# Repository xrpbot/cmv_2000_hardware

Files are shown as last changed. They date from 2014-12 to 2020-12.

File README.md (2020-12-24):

CMV2000 adapter kit
===================

This adapter kit allows connecting an [AMS CMV2000](https://ams.com/cmv2000)
image sensor to a ZedBoard (and probably other FPGA devboards) via the [FPGA
Mezzanine Card (FMC)](https://en.wikipedia.org/wiki/FPGA_Mezzanine_Card)
connector.

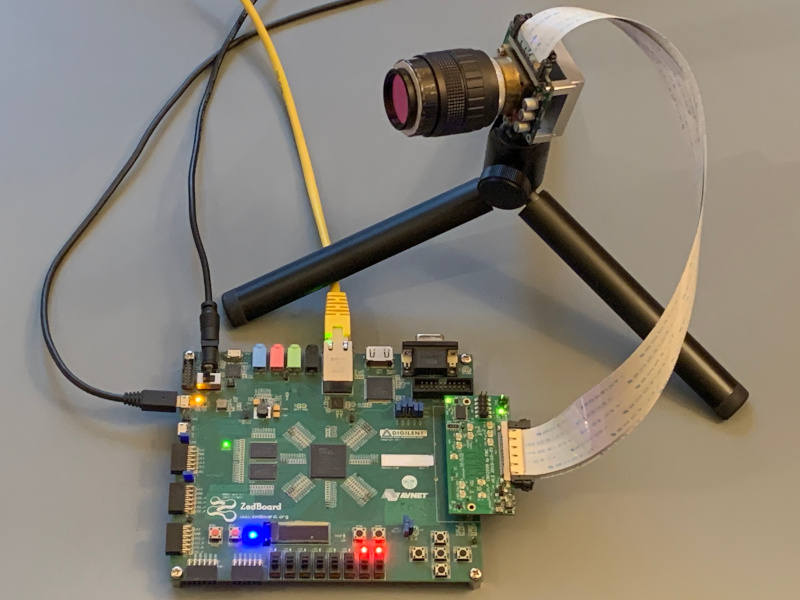
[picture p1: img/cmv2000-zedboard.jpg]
Image: CMV2000 sensor and ZedBoard


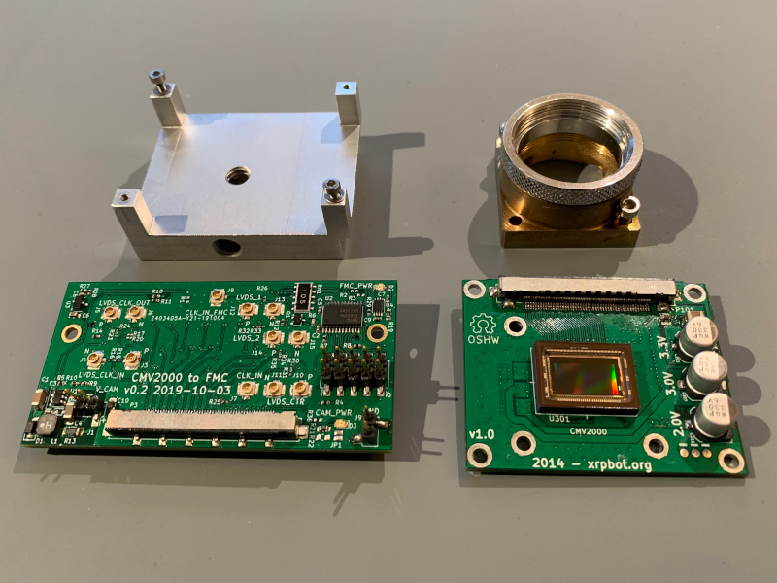
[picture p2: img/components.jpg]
Image: PCBs and machined parts


The CMV2000 is a high-speed image sensor intended for machine vision
applications (2 megapixels, 340 fps). While relatively expensive, it is one of
the few mid-range image sensors where reasonably complete documentation is
freely available (without NDA) from the manufacturer.

The hardware is split in two PCBs, connected by two high speed flat flex
cables. The first board contains the sensor, the second board connects to the
FMC port on the ZedBoard.

The sensor is powered by the ZedBoard, using the 12 V supply provided on the FMC
connector. Level shifters are used to translate all single-ended signals from
the FPGA I/O voltage to the 3.3 V used by the sensor.

The FMC board contains integrated 1k probes for some of the high-speed
differential signals. Additionally, a pin header allows probing the low-speed
single-ended signals.

For space reasons, the 1k probes use U.FL connectors for the connection to the
oscilloscope. The U.FL connectors have a very limited number of mating cycles
and the number of connections must therefore be kept to a minimum. Note that a
1k probe generally requires a termination (typically 50 Ω) at the oscilloscope;
with a high-impedance input, results will be very poor. If the 1k probes are
not required, the connectors and the corresponding resistors can simply be left
unpopulated.

See [pinmap.txt](pinmap.txt) for a list of connections from FPGA package pins
to camera pins.

Note that this repository uses submodules.

FMC board
---------

### Stackup

The FMC PCB is designed to be produced with 4 layers using the
[JLCPCB](https://jlcpcb.com/) JLC2313 stackup. (0.1 mm prepreg, ε<sub>r</sub> =
4.05 between the outer and inner layer.)

Using the JLCPCB impedance calculator, the following trace parameters were obtained:

100 Ω differential:
4.00 mil (102 µm) trace width / 5.00 mil (127 µm) space

50 Ω single-ended:
5.78 mil (147 µm) trace width

These results were cross-checked using Maarten Baerts [AlterPCB
TLineSim](https://www.maartenbaert.be/alterpcb/tlinesim/) tool. In addition,
the influence of ground pour on the signal layer was investigated (using the
"Coplanar Waveguide" geometry). A distance of >= 200 µm between the edge of the
signal trace and ground seems to have little effect on the impedance.

### Vias

JLC multilayer: min. via drill: 0.2 mm, min. via diameter: 0.45 mm

Known issues
------------

* Sensor board: The 3.0 V rail is generated with an LDO (U202) from the 3.3 V
rail. However, this drop is too low for the LDO to properly operate. On the
physical board, this is fixed with a bodge wire connecting the input of U202 to
the 5.0 V rail instead. However, this fix is not contained in the schematic or
layout.

* After the sensor board PCB was produced, we found out that the intended
31-pin connector (P102) was no longer available. Thus, a 41-pin connector had
to be bodged on (sacrificing the I2C EEPROM). This change is not documented in
the schematic. However, when the current version of the FMC board was designed,
it was adapted to the situation and uses a 41-pin connector. The end result is
that the boards, as found in this repository, are incompatible: the sensor
board uses a 51-pin and a 31-pin connector, while the FMC board uses a 51-pin
and a 41-pin connector.

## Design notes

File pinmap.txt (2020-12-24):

VHDL (Note 1)         Zynq_pkg Zynq                          Zedboard       FMC    JST/Adapter    JST/Camera    CMV2000           Comment

                                                                            n/a    J51/51         J51/1         LED
                                                                            -      J51/50         J51/2         EEPROM_A0
                      U7       Bank13-IO_25                  FMC-SDA        C31    J51/49         J51/3         EEPROM_SDA        optional (jumper)
                      R7       Bank13-IO_0                   FMC-SCL        C30    J51/48         J51/4         EEPROM_SCL        optional (jumper)

                      R19      Bank34-IO_L22P_T3             FMC-LA10_P     C14    CAM_PWR_ON     -             -                 optional (jumper)
                      P17      Bank34-IO_L20P_T3             FMC-LA02_P     H7     CAM_PWR_GOOD   -             -                 optional (jumper)

cmv_sys_res_n         T19      Bank34-IO_L22N_T3             FMC-LA10_N     C15    J51/47         J51/5         SYS_RES_N

spi_en                K20      Bank34-IO_L11N_T1_SRCC        FMC-LA14_N     C19    J51/43         J51/9         SPI_EN
spi_clk               K19      Bank34-IO_L11P_T1_SRCC        FMC-LA14_P     C18    J51/45         J51/7         SPI_CLK
spi_in                C20      Bank35-IO_L14N_T2_AD4N_SRCC   FMC-LA18_CC_N  C23    J51/39         J51/13        SPI_IN
spi_out               D20      Bank35-IO_L14P_T2_AD4P_SRCC   FMC-LA18_CC_P  C22    J51/41         J51/11        SPI_OUT

cmv_clk_in            E21      Bank35-IO_L17P_T2_AD5P        FMC-LA27_P     C26    J51/31         J51/21        CLK_IN
cmv_t_exp1            L21      Bank34-IO_L10P_T1             FMC-LA06_P     C10    J51/37         J51/15        T_EXP1            pin assignment changed (Note 2)
cmv_t_exp2            L22      Bank34-IO_L10N_T1             FMC-LA06_N     C11    J51/35         J51/17        T_EXP2            pin assignment changed (Note 2)
cmv_frame_req         D21      Bank35-IO_L17N_T2_AD5N        FMC-LA27_N     C27    J51/33         J51/19        FRAME_REQ

cmv_lvds_outclk_n     C19      Bank35-IO_L12N_T1_MRCC        FMC-CLK1_N     G3     J51/2          J51/50        LVDS_CLK_OUT_N
cmv_lvds_outclk_p     D18      Bank35-IO_L12P_T1_MRCC        FMC-CLK1_P     G2     J51/1          J51/51        LVDS_CLK_OUT_P

cmv_lvds_clk_n        L19      Bank34-IO_L12N_T1_MRCC        FMC-CLK0_N     H5     J41/16         J31/26        LVDS_CLK_IN_N     optional (jumper)
cmv_lvds_clk_p        L18      Bank34-IO_L12P_T1_MRCC        FMC-CLK0_P     H4     J41/17         J31/25        LVDS_CLK_IN_P     optional (jumper)

cmv_lvds_ctrl_n       A22      Bank35-IO_L15N_T2_DQS_AD12N   FMC-LA32_N     H38    J51/29         J51/23        LVDS_CTR_N
cmv_lvds_ctrl_p       A21      Bank35-IO_L15P_T2_DQS_AD12P   FMC-LA32_P     H37    J51/28         J51/24        LVDS_CTR_P

cmv_lvds_data_n[0]    E18      Bank35-IO_L5N_T0_AD9N         FMC-LA26_N     D27    J41/19         J31/23        LVDS_1_N
cmv_lvds_data_p[0]    F18      Bank35-IO_L5P_T0_AD9P         FMC-LA26_P     D26    J41/20         J31/22        LVDS_1_P
cmv_lvds_data_n[1]    B15      Bank35-IO_L7N_T1_AD2N         FMC-LA30_N     H35    J51/26         J51/26        LVDS_2_N
cmv_lvds_data_p[1]    C15      Bank35-IO_L7P_T1_AD2P         FMC-LA30_P     H34    J51/25         J51/27        LVDS_2_P
cmv_lvds_data_n[2]    A19      Bank35-IO_L10N_T1_AD11N       FMC-LA24_N     H29    J51/20         J51/32        LVDS_3_N
cmv_lvds_data_p[2]    A18      Bank35-IO_L10P_T1_AD11P       FMC-LA24_P     H28    J51/19         J51/33        LVDS_3_P
cmv_lvds_data_n[3]    A17      Bank35-IO_L9N_T1_DQS_AD3N     FMC-LA28_N     H32    J51/23         J51/29        LVDS_4_N
cmv_lvds_data_p[3]    A16      Bank35-IO_L9P_T1_DQS_AD3P     FMC-LA28_P     H31    J51/22         J51/30        LVDS_4_P
cmv_lvds_data_n[4]    D15      Bank35-IO_L3N_T0_DQS_AD1N     FMC-LA23_N     D24    J41/22         J31/20        LVDS_5_N
cmv_lvds_data_p[4]    E15      Bank35-IO_L3P_T0_DQS_AD1P     FMC-LA23_P     D23    J41/23         J31/19        LVDS_5_P
cmv_lvds_data_n[5]    B20      Bank35-IO_L13N_T2_MRCC        FMC-LA17_CC_N  D21    J41/25         J31/17        LVDS_6_N
cmv_lvds_data_p[5]    B19      Bank35-IO_L13P_T2_MRCC        FMC-LA17_CC_P  D20    J41/26         J31/16        LVDS_6_P
cmv_lvds_data_n[6]    J17      Bank34-IO_L2N_T0              FMC-LA15_N     H20    J51/11         J51/41        LVDS_7_N
cmv_lvds_data_p[6]    J16      Bank34-IO_L2P_T0              FMC-LA15_P     H19    J51/10         J51/42        LVDS_7_P
cmv_lvds_data_n[7]    E20      Bank35-IO_L21N_T3_DQS_AD14N   FMC-LA21_N     H26    J51/17         J51/35        LVDS_8_N
cmv_lvds_data_p[7]    E19      Bank35-IO_L21P_T3_DQS_AD14P   FMC-LA21_P     H25    J51/16         J51/36        LVDS_8_P
cmv_lvds_data_n[8]    G16      Bank35-IO_L4N_T0              FMC-LA19_N     H23    J51/14         J51/38        LVDS_9_N
cmv_lvds_data_p[8]    G15      Bank35-IO_L4P_T0              FMC-LA19_P     H22    J51/13         J51/39        LVDS_9_P
cmv_lvds_data_n[9]    N18      Bank34-IO_L5N_T0              FMC-LA11_N     H17    J51/8          J51/44        LVDS_10_N
cmv_lvds_data_p[9]    N17      Bank34-IO_L5P_T0              FMC-LA11_P     H16    J51/7          J51/45        LVDS_10_P
cmv_lvds_data_n[10]   M17      Bank34-IO_L4N_T0              FMC-LA13_N     D18    J41/28         J31/14        LVDS_11_N
cmv_lvds_data_p[10]   L17      Bank34-IO_L4P_T0              FMC-LA13_P     D17    J41/29         J31/13        LVDS_11_P
cmv_lvds_data_n[11]   R21      Bank34-IO_L17N_T2             FMC-LA09_N     D15    J41/31         J31/11        LVDS_12_N
cmv_lvds_data_p[11]   R20      Bank34-IO_L17P_T2             FMC-LA09_P     D14    J41/32         J31/10        LVDS_12_P
cmv_lvds_data_n[12]   M22      Bank34-IO_L15N_T2_DQS         FMC-LA04_N     H11    J51/5          J51/47        LVDS_13_N
cmv_lvds_data_p[12]   M21      Bank34-IO_L15P_T2_DQS         FMC-LA04_P     H10    J51/4          J51/48        LVDS_13_P
cmv_lvds_data_n[13]   K18      Bank34-IO_L7N_T1              FMC-LA05_N     D12    J41/34         J31/8         LVDS_14_N
cmv_lvds_data_p[13]   J18      Bank34-IO_L7P_T1              FMC-LA05_P     D11    J41/35         J31/7         LVDS_14_P
cmv_lvds_data_n[14]   T17      Bank34-IO_L21N_T3_DQS         FMC-LA07_N     H14    J41/40         J31/2         LVDS_15_N
cmv_lvds_data_p[14]   T16      Bank34-IO_L21P_T3_DQS         FMC-LA07_P     H13    J41/41         J31/1         LVDS_15_P
cmv_lvds_data_n[15]   N20      Bank34-IO_L14N_T2_SRCC        FMC-LA01_CC_N  D9     J41/37         J31/5         LVDS_16_N
cmv_lvds_data_p[15]   N19      Bank34-IO_L14P_T2_SRCC        FMC-LA01_CC_P  D8     J41/38         J31/4         LVDS_16_P

Note 1: The "VHDL" column refers to the Apertus gateware.
Note 2: Pin assignment changed with respect to the obsolete v0.1 of the FMC adapter board.

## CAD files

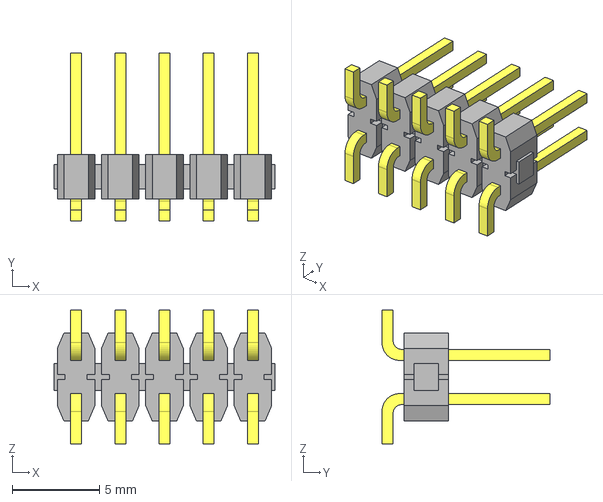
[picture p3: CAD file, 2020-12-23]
fmc_board/3dmodels/TSM-105-01-L-DV.stp
12.7 x 9.65 x 7.70 mm
_TSM-105-01-DV_body
_T-1S6-16(-01-5-DV)

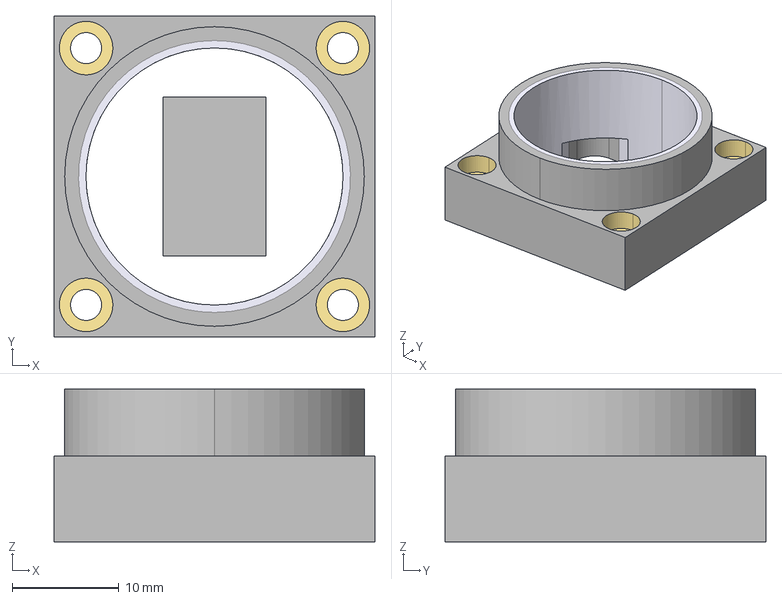
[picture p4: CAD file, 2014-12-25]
mount/c-mount.stp
30.0 x 30.0 x 14.3 mm

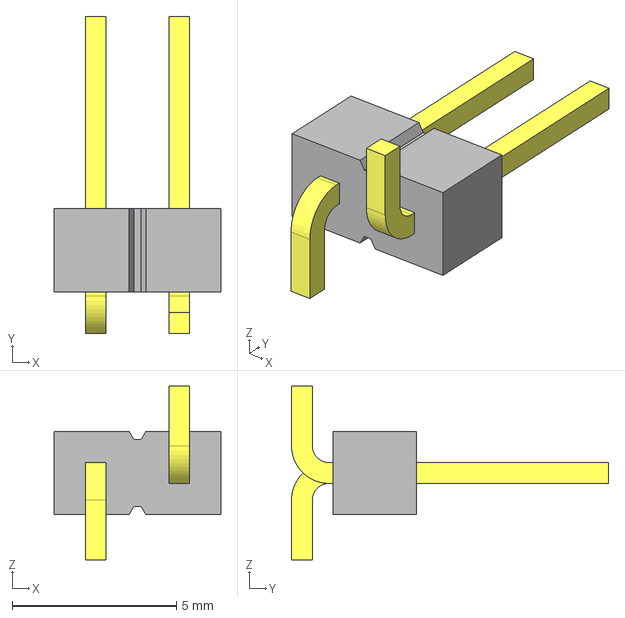
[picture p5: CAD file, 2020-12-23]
fmc_board/3dmodels/TSM-102-01-L-SV.stp
5.08 x 9.65 x 5.28 mm
_TSM-102-01-SV_body
_T-1S6-16(-01-2-SV)

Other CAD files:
mount/c-mount.stl

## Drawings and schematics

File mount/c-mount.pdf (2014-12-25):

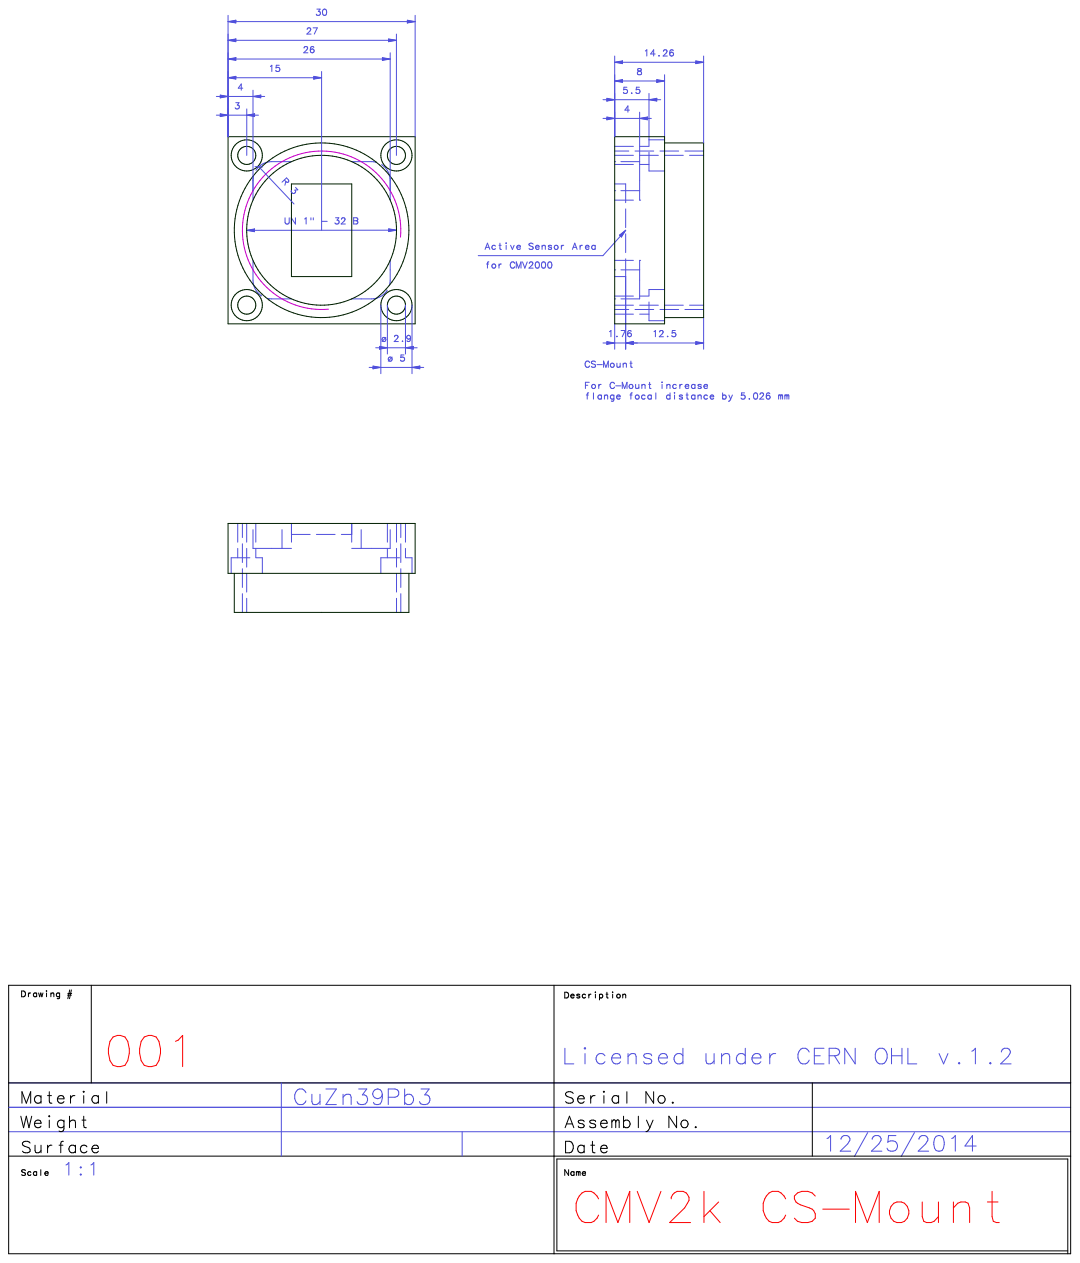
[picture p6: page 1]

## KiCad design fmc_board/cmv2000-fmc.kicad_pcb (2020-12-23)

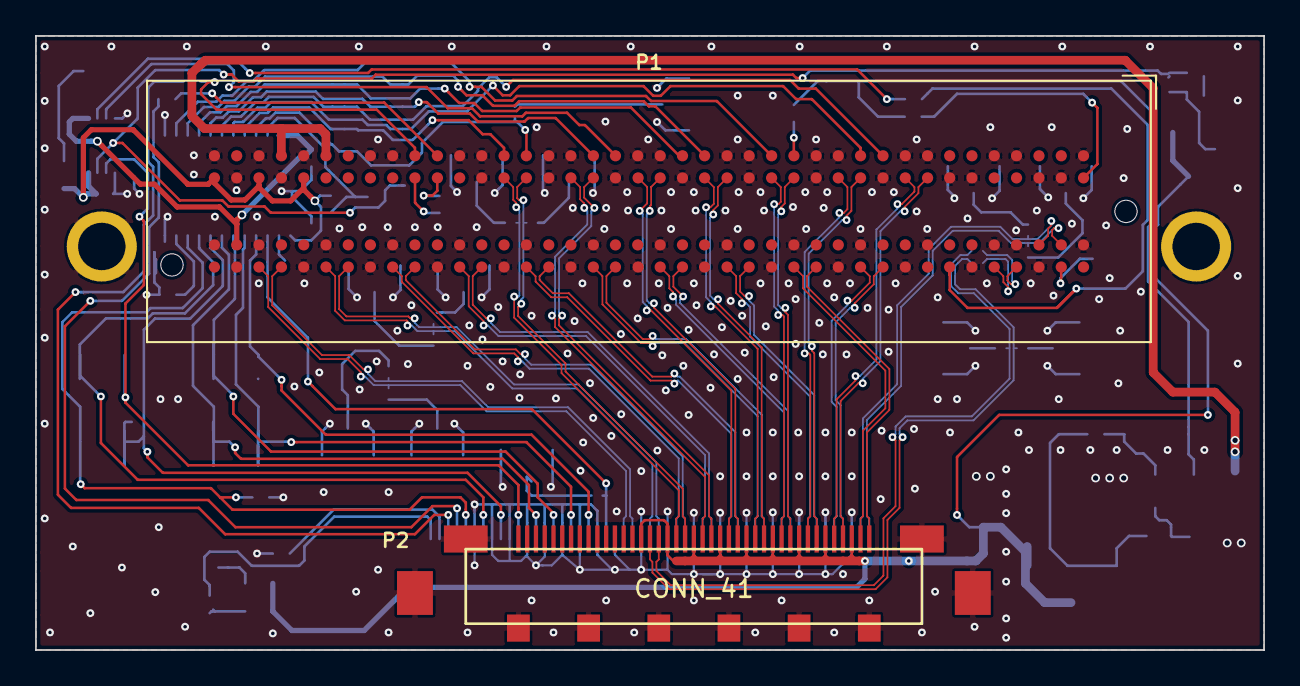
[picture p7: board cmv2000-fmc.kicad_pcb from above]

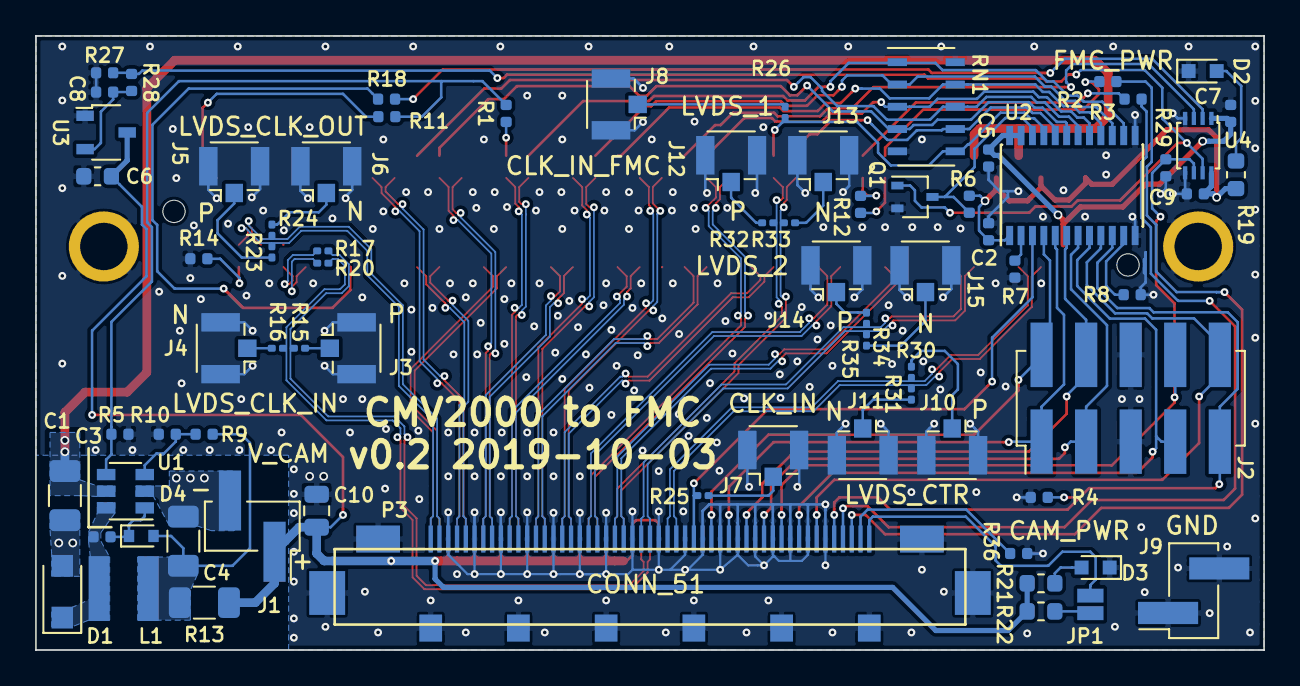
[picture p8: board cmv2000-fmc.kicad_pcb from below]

Board: 4 copper layers, 70.0 x 35.0 mm, 76 parts (74 on the bottom side), 101 nets.

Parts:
C1: 10uF, 25V; C_1206_3216Metric
C2, C5, C7, C9: 100n; C_0402_1005Metric
C3: 10n; C_0402_1005Metric
C4: 22uF, 10V; C_1206_3216Metric
C6: 1u; C_0603_1608Metric
C8: 1n; C_0402_1005Metric
C10: TBD; C_0805_2012Metric
D1: D; NRVTS245ESF
D2, D3: LED; 150060VS75000
D4: D; D_SOD-523
J1, J9: Conn_01x02; TSM-102-01-L-SV
J2: Conn_02x05; TSM-105-01-L-DV
J3: LVDS_CLK_IN_P; U.FL_Hirose_U.FL-R-SMT-1_Vertical
J4: LVDS_CLK_IN_N; U.FL_Hirose_U.FL-R-SMT-1_Vertical
J5: LVDS_CLK_OUT_P; U.FL_Hirose_U.FL-R-SMT-1_Vertical
J6: LVDS_CLK_OUT_N; U.FL_Hirose_U.FL-R-SMT-1_Vertical
J7, J8: CLK_IN; U.FL_Hirose_U.FL-R-SMT-1_Vertical
J10: LVDS_CTR_P; U.FL_Hirose_U.FL-R-SMT-1_Vertical
J11: LVDS_CTR_N; U.FL_Hirose_U.FL-R-SMT-1_Vertical
J12: LVDS_1_P; U.FL_Hirose_U.FL-R-SMT-1_Vertical
J13: LVDS_1_N; U.FL_Hirose_U.FL-R-SMT-1_Vertical
J14: LVDS_2_P; U.FL_Hirose_U.FL-R-SMT-1_Vertical
J15: LVDS_2_N; U.FL_Hirose_U.FL-R-SMT-1_Vertical
JP1: JUMPER; SOLDERSW_2
L1: 4.7uH; NRS4018
P1: FMC_LPC; Samtec_FMC_ASP-134604-01_4x40_Vertical
P2: CONN_41; FI-RE41S-HF-R1500
P3: CONN_51; FI-RE51S-HF-R1500
Q1: Q_NMOS_GSD; SOT-323_SC-70
R1, R2, R3, R36: DNP; R_0402_1005Metric
R4, R5, R6, R7, R8, R28: 10k; R_0402_1005Metric
R9: 49.9k; R_0402_1005Metric
R10: 9.53k; R_0402_1005Metric
R11, R12, R14, R18: 0; R_0402_1005Metric
R13: 0; R_1206_3216Metric
R15, R16, R23, R24, R25, R26, R30, R31, R32, R33, R34, R35: 1k; R_0201_0603Metric
R17, R20: DNP; R_0201_0603Metric
R19: 270R; R_0603_1608Metric
R21: 620R; R_0603_1608Metric
R22: TBD; R_0603_1608Metric
R27: 33k; R_0402_1005Metric
R29: 1M; R_0402_1005Metric
RN1: R_NET_BUS_8, 1M; EXB-A10P
U1: AP3211; SOT-23-6
U2: SN74AXC8T245; TSSOP-24_4.4x7.8mm_P0.65mm
U3: BD49xxx_GND1; SSOP3
U4: SN74LVC2T45; VSSOP-8_2.4x2.1mm_P0.5mm

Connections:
+3V3: C2.1, C9.1, P1.D36, P1.D38, P1.D40, R6.1, R19.1, U2.1, U4.8
+12V: C1.1, P1.C35, P1.C37, U1.5
/5V_CAM: C6.1, C10.1, J1.1, P2.15, P2.18, P2.21, P2.24, P2.27, P2.30, P2.33, P2.36, P2.39, R13.1, R21.1, R22.2, U3.3
/A0: P3.50, R36.2
/CAM_PWR_GOOD: Q1.1, R27.1, R28.1, U4.7
/CAM_PWR_GOOD_FMC: R18.1, U4.2
/CAM_PWR_ON: R1.2, R5.1, R11.1, U1.4
/CLK_IN: P3.31, R25.2, U2.3
/CLK_IN_FMC: P1.C26, R26.2, RN1.6, U2.21
/FRAME_REQ: J2.2, P3.33, U2.4
/FRAME_REQ_FMC: P1.C27, RN1.7, U2.20
/LED: JP1.2, P3.51
/LVDS_1_N: P1.D27, P2.19, R33.2
/LVDS_1_P: P1.D26, P2.20, R32.2
/LVDS_2_N: P1.H35, P3.26, R35.2
/LVDS_2_P: P1.H34, P3.25, R34.2
/LVDS_3_N: P1.H29, P3.20
/LVDS_3_P: P1.H28, P3.19
/LVDS_4_N: P1.H32, P3.23
/LVDS_4_P: P1.H31, P3.22
/LVDS_5_N: P1.D24, P2.22
/LVDS_5_P: P1.D23, P2.23
/LVDS_6_N: P1.D21, P2.25
/LVDS_6_P: P1.D20, P2.26
/LVDS_7_N: P1.H20, P3.11
/LVDS_7_P: P1.H19, P3.10
/LVDS_8_N: P1.H26, P3.17
/LVDS_8_P: P1.H25, P3.16
/LVDS_9_N: P1.H23, P3.14
/LVDS_9_P: P1.H22, P3.13
/LVDS_10_N: P1.H17, P3.8
/LVDS_10_P: P1.H16, P3.7
/LVDS_11_N: P1.D18, P2.28
/LVDS_11_P: P1.D17, P2.29
/LVDS_12_N: P1.D15, P2.31
/LVDS_12_P: P1.D14, P2.32
/LVDS_13_N: P1.H11, P3.5
/LVDS_13_P: P1.H10, P3.4
/LVDS_14_N: P1.D12, P2.34
/LVDS_14_P: P1.D11, P2.35
/LVDS_15_N: P1.H14, P2.40
/LVDS_15_P: P1.H13, P2.41
/LVDS_16_N: P1.D09, P2.37
/LVDS_16_P: P1.D08, P2.38
/LVDS_CLK_IN_0_N: P1.H05, R20.2
/LVDS_CLK_IN_0_P: P1.H04, R17.2
/LVDS_CLK_IN_N: P2.16, R16.2, R20.1
/LVDS_CLK_IN_P: P2.17, R15.2, R17.1
/LVDS_CLK_OUT_N: P1.G03, P3.2, R24.2
/LVDS_CLK_OUT_P: P1.G02, P3.1, R23.2
/LVDS_CTR_N: P1.H38, P3.29, R31.2
/LVDS_CTR_P: P1.H37, P3.28, R30.2
/SCL: P3.48, R3.2
/SDA: P3.49, R2.2
/SPI_CLK: J2.10, P3.45, U2.9
/SPI_CLK_FMC: P1.C18, RN1.2, U2.15
/SPI_EN: J2.7, P3.43, U2.8
/SPI_EN_FMC: P1.C19, RN1.9, U2.16
/SPI_IN: J2.3, P3.39, U2.7
/SPI_IN_FMC: P1.C23, RN1.3, U2.17
/SPI_OUT: J2.8, P3.41, R29.1, U4.6
/SPI_OUT_FMC: P1.C22, U4.3
/SYS_RES_N: J2.9, P3.47, R4.1, U2.10
/SYS_RES_N_FMC: P1.C15, RN1.1, U2.14
/T_EXP1: J2.4, P3.37, U2.6
/T_EXP1_FMC: P1.C10, RN1.8, U2.18
/T_EXP2: J2.1, P3.35, U2.5
/T_EXP2_FMC: P1.C11, RN1.4, U2.19
/VIO_FMC: C5.1, C7.1, P1.G39, U2.23, U2.24, U4.1
GND: C1.2, C2.2, C4.2, C5.2, C6.2, C7.2, C8.2, C9.2, C10.2, D1.2, D2.1, D3.1, J1.2, J2.5, J2.6, J3.2, J4.2, J5.2, J6.2, J7.2, J8.2, J9.1, J9.2, J10.2, J11.2, J12.2, J13.2, J14.2, J15.2, P1.C01, P1.C04, P1.C05, P1.C08, P1.C09, P1.C12, P1.C13, P1.C16, P1.C17, P1.C20, P1.C21, P1.C24, P1.C25, P1.C28, P1.C29, P1.C32, P1.C33, P1.C36, P1.C38, P1.C40, P1.D02, P1.D03, P1.D06, P1.D07, P1.D10, P1.D13, P1.D16, P1.D19, P1.D22, P1.D25, P1.D28, P1.D37, P1.D39, P1.G01, P1.G04, P1.G05, P1.G08, P1.G11, P1.G14, P1.G17, P1.G20, P1.G23, P1.G26, P1.G29, P1.G32, P1.G35, P1.G38, P1.G40, P1.H03, P1.H06, P1.H09, P1.H12, P1.H15, P1.H18, P1.H21, P1.H24, P1.H27, P1.H30, P1.H33, P1.H36, P1.H39, P2.SH, P3.3, P3.6, P3.9, P3.12, P3.15, P3.18, P3.21, P3.24, P3.27, P3.30, P3.32, P3.34, P3.36, P3.38, P3.40, P3.42, P3.44, P3.46, P3.SH, Q1.2, R4.2, R5.2, R7.2, R8.2, R10.2, R14.1, R27.2, R29.2, R36.1, RN1.5, RN1.10, U1.2, U2.12, U2.13, U3.1, U4.4, U4.5
unnamed: C3.1, D4.1, U1.1
unnamed: C3.2, D1.1, L1.1, U1.6
unnamed: C4.1, D4.2, L1.2, R9.1, R13.2
unnamed: C8.1, R28.2, U3.2
unnamed: D2.2, R19.2
unnamed: D3.2, R21.2
unnamed: J3.1, R15.1
unnamed: J4.1, R16.1
unnamed: J5.1, R23.1
unnamed: J6.1, R24.1
unnamed: J7.1, R25.1
unnamed: J8.1, R26.1
unnamed: J10.1, R30.1
unnamed: J11.1, R31.1
unnamed: J12.1, R32.1
unnamed: J13.1, R33.1
unnamed: J14.1, R34.1
unnamed: J15.1, R35.1
unnamed: JP1.1, R22.1
unnamed: P1.C14, R1.1
unnamed: P1.C30, R3.1
unnamed: P1.C31, R2.1
unnamed: P1.D01, R11.2
unnamed: P1.D30, R12.1
unnamed: P1.D31, R12.2
unnamed: P1.H02, R14.2
unnamed: P1.H07, R18.2
unnamed: Q1.3, R6.2, U2.22
unnamed: R7.1, U2.2
unnamed: R8.1, U2.11
unnamed: R9.2, R10.1, U1.3

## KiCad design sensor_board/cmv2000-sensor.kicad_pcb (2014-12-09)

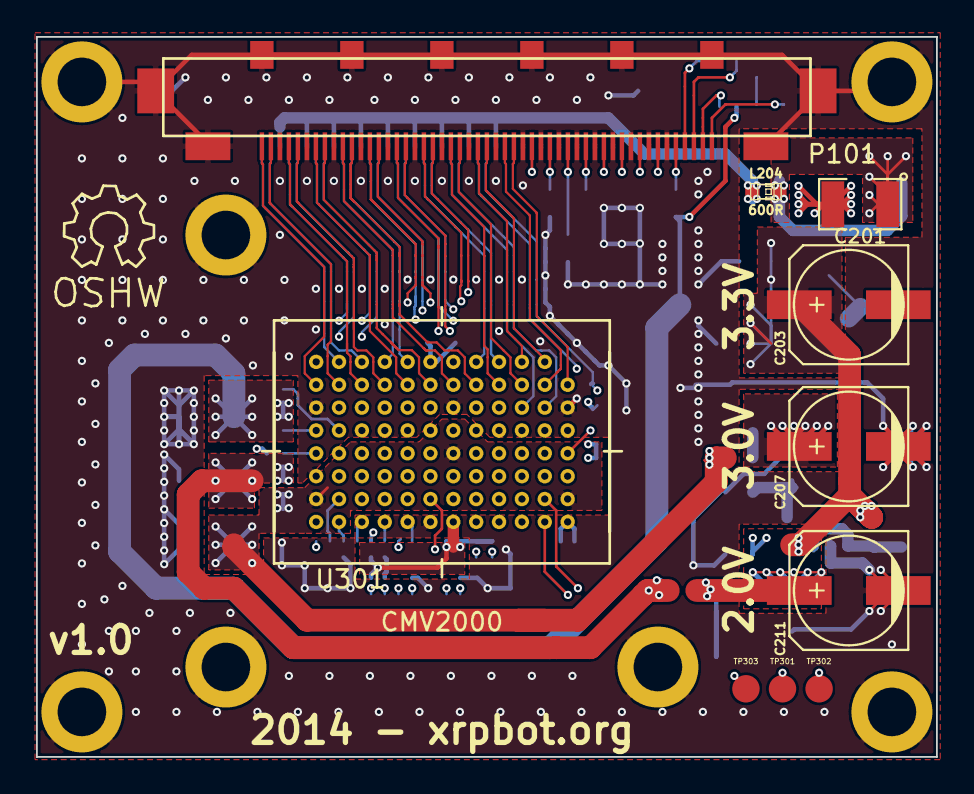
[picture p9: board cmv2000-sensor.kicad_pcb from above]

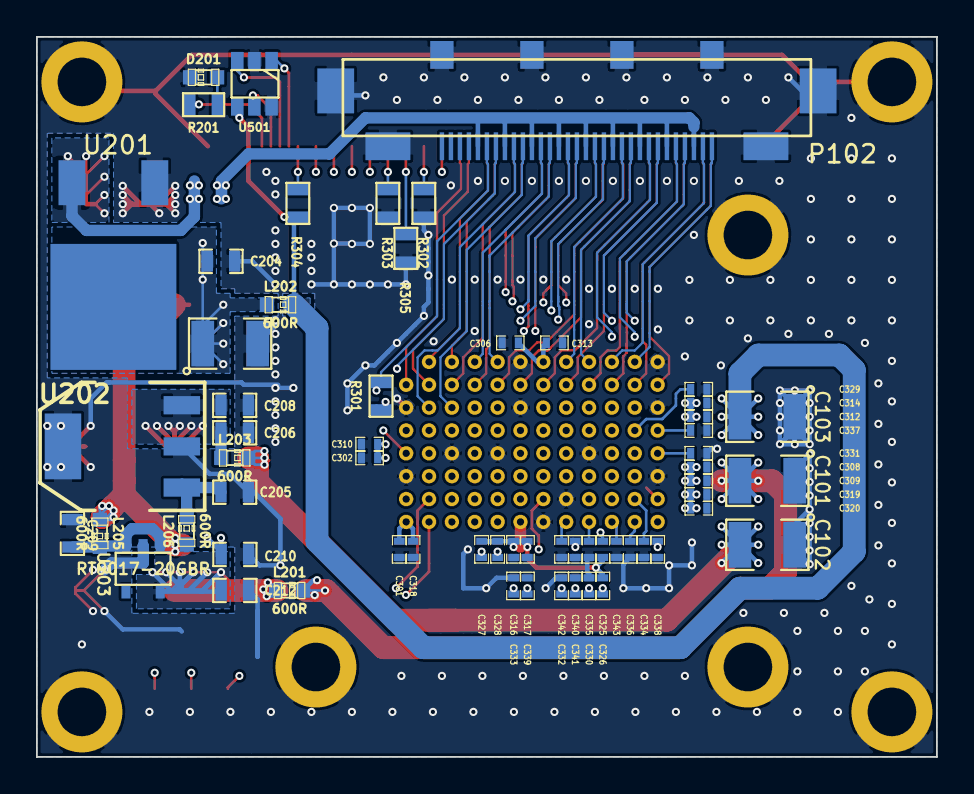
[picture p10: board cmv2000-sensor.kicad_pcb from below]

Board: 4 copper layers, 50.0 x 40.0 mm, 79 parts (61 on the bottom side), 85 nets.

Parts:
C101, C102, C103, C201, C202: 100µ; SM1210
C203, C207, C211: 330µ; c_elec_6.3x7.7
C204, C208, C212: 33µ; SM0603_Capa
C205, C206: 10µ; SM0603_Capa
C209, C210: 1µ; SM0603_Capa
C301, C309, C310, C313, C314, C317, C319: 4.7µ; SM0402_c
C302, C306, C308, C312, C316, C318, C320, C325, C326, C327, C328, C329, C330, C331, C332, C333, C334, C335, C336, C337, C338, C339, C340, C341, C342, C343: 100n; SM0402_c
D201: LED; LED-0603
L201, L202, L203, L204, L205, L206: 600R; LED-0603
P101: FI-RE51S-HF-R1500
P102: CONN_31; FI-RE31S-HF-R1500
R201: 680; SM0603
R301: 100; SM0603
R302, R303, R305: R; SM0603
R304: 10k; SM0603
SYM: Symbol_OSHW-Logo_SilkScreen_07Jul2012; Symbol_OSHW-Logo_SilkScreen
TP301, TP302, TP303: TESTPOINT; Measurement_Point_Round-SMD-Pad_Small
U201: AP1084; TO252-3
U202: MCP1826S; SOT223
U203: RT9017-20GBR; SOT23-5
U301: CMV2000
U401, U402, U403, U404, U405, U407, U408: MOUNTHOLE; MOUNTING_HOLE
U501: 24AA025E48; SOT23_6

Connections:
/CMV2000/2.0V: C101.2, C306.2, C308.2, C309.2, C313.2, L201.2, U301.A7, U301.C7, U301.E4, U301.E7, U301.E8
/CMV2000/3.0V: C102.2, C319.2, C320.2, L203.2, U301.E6, U301.G1, U301.G12
/CMV2000/3.3V: C103.2, C301.2, C302.2, C310.2, C312.2, C314.2, C316.2, C317.2, C318.2, C325.1, C326.1, C327.1, C328.1, L202.2, R304.1, U301.E2, U301.F7, U301.H1, U301.H6, U501.4
/CMV2000/CLK_IN: P101.21, U301.E1
/CMV2000/FRAME_REQ: P101.19, R302.1, U301.F2
/CMV2000/LVDS_1_N: P102.23, U301.C2
/CMV2000/LVDS_1_P: P102.22, U301.C3
/CMV2000/LVDS_2_N: P101.26, U301.A2
/CMV2000/LVDS_2_P: P101.27, U301.A3
/CMV2000/LVDS_3_N: P101.32, U301.D3
/CMV2000/LVDS_3_P: P101.33, U301.D4
/CMV2000/LVDS_4_N: P101.29, U301.B3
/CMV2000/LVDS_4_P: P101.30, U301.B4
/CMV2000/LVDS_5_N: P102.20, U301.A4
/CMV2000/LVDS_5_P: P102.19, U301.A5
/CMV2000/LVDS_6_N: P102.17, U301.C4
/CMV2000/LVDS_6_P: P102.16, U301.C5
/CMV2000/LVDS_7_N: P101.41, U301.B5
/CMV2000/LVDS_7_P: P101.42, U301.B6
/CMV2000/LVDS_8_N: P101.35, U301.D5
/CMV2000/LVDS_8_P: P101.36, U301.D6
/CMV2000/LVDS_9_N: P101.38, U301.D7
/CMV2000/LVDS_9_P: P101.39, U301.D8
/CMV2000/LVDS_10_N: P101.44, U301.B7
/CMV2000/LVDS_10_P: P101.45, U301.B8
/CMV2000/LVDS_11_N: P102.14, U301.C8
/CMV2000/LVDS_11_P: P102.13, U301.C9
/CMV2000/LVDS_12_N: P102.11, U301.A8
/CMV2000/LVDS_12_P: P102.10, U301.A9
/CMV2000/LVDS_13_N: P101.47, U301.B9
/CMV2000/LVDS_13_P: P101.48, U301.B10
/CMV2000/LVDS_14_N: P102.8, U301.D9
/CMV2000/LVDS_14_P: P102.7, U301.D10
/CMV2000/LVDS_15_N: P102.2, U301.A10
/CMV2000/LVDS_15_P: P102.1, U301.A11
/CMV2000/LVDS_16_N: P102.5, U301.C10
/CMV2000/LVDS_16_P: P102.4, U301.C11
/CMV2000/LVDS_CLK_IN_N: P102.26, R301.1, U301.D2
/CMV2000/LVDS_CLK_IN_P: P102.25, R301.2, U301.D1
/CMV2000/LVDS_CLK_OUT_N: P101.50, U301.B11
/CMV2000/LVDS_CLK_OUT_P: P101.51, U301.B12
/CMV2000/LVDS_CTR_N: P101.23, U301.B1
/CMV2000/LVDS_CTR_P: P101.24, U301.B2
/CMV2000/SPI_CLK: P101.7, U301.H4
/CMV2000/SPI_EN: P101.9, U301.G4
/CMV2000/SPI_IN: P101.13, U301.F3
/CMV2000/SPI_OUT: P101.11, U301.F4
/CMV2000/SYS_RES_N: P101.5, R304.2, U301.H5
/CMV2000/T_EXP1: P101.15, R303.1, U301.H3
/CMV2000/T_EXP2: P101.17, R305.1, U301.G3
/Power Supply/5V: L204.1, P102.3, P102.6, P102.9, P102.12, P102.15, P102.18, P102.21, P102.24, P102.27
/Power Supply/LED_3.3V: P101.1, R201.2
/Sheet53D8E0E2/A0: P101.2, U501.5
/Sheet53D8E0E2/SCL: P101.4, U501.1
/Sheet53D8E0E2/SDA: P101.3, U501.3
GND: C101.1, C102.1, C103.1, C201.2, C202.2, C203.2, C204.2, C205.2, C206.2, C207.2, C208.2, C209.2, C210.2, C211.2, C212.2, C301.1, C302.1, C306.1, C308.1, C309.1, C310.1, C312.1, C313.1, C314.1, C316.1, C317.1, C318.1, C319.1, C320.1, C329.1, C330.1, C331.1, C332.1, C333.1, C334.1, C335.1, C336.1, C337.1, C338.1, C339.1, C340.1, C341.1, C342.1, C343.1, D201.2, P101.6, P101.8, P101.10, P101.12, P101.14, P101.16, P101.18, P101.20, P101.22, P101.25, P101.28, P101.31, P101.34, P101.37, P101.40, P101.43, P101.46, P101.49, P101.52, P101.53, P101.54, P101.55, P101.56, P101.57, P101.58, P101.59, P101.60, P101.61, P102.32, P102.33, P102.34, P102.35, P102.36, P102.37, P102.38, P102.39, R302.2, R303.2, R305.2, U201.1, U202.2, U202.4, U203.2, U301.A6, U301.A12, U301.C1, U301.C6, U301.C12, U301.E3, U301.E5, U301.E9, U301.F1, U301.F12, U301.G8, U301.H7, U401.1, U402.1, U403.1, U404.1, U405.1, U407.1, U408.1, U501.2, U501.6
unnamed: C201.1, L204.2, U201.3
unnamed: C202.1, C203.1, C204.1, L202.1, L205.1, L206.1, U201.2
unnamed: C205.1, L206.2, U202.1
unnamed: C206.1, C207.1, C208.1, L203.1, U202.3
unnamed: C209.1, L205.2, U203.1, U203.3
unnamed: C210.1, C211.1, C212.1, L201.1, U203.5
unnamed: C325.2, U301.F10
unnamed: C326.2, U301.G10
unnamed: C327.2, U301.F5
unnamed: C328.2, U301.G5
unnamed: C329.2, U301.D11
unnamed: C330.2, U301.E10
unnamed: C331.2, U301.E12
unnamed: C332.2, U301.F8
unnamed: C333.2, U301.G6
unnamed: C334.2, U301.G11
unnamed: C335.2, U301.H9
unnamed: C336.2, U301.H11
unnamed: C337.2, U301.D12
unnamed: C338.2, U301.E11
unnamed: C339.2, U301.F6
unnamed: C340.2, U301.F9
unnamed: C341.2, U301.G9
unnamed: C342.2, U301.H8
unnamed: C343.2, U301.H10
unnamed: D201.1, R201.1
unnamed: TP301.1, U301.H2
unnamed: TP302.1, U301.G2
unnamed: TP303.1, U301.G7

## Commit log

2014-07-20 basic routing done
    [CMV2000.sch, c-mount.stp, mountingholes.sch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]
2014-07-20 remove now obsolete fmc lib
    [fmc.sch]
2014-07-20 fix some GND vias that were hanging in midair
    [stereo_vision_cmv2000.kicad_pcb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]
2014-07-28 change 0.5mm pitch to 0.3mm pitch connector and add proper ground between all LVDS pairs.
    [CMV2000.sch, I2C.sch, mountingholes.sch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]
2014-10-01 Increase via size
    [stereo_vision_cmv2000.kicad_pcb]
2014-12-08 rework connector design and differential routing
    [CMV2000.sch, I2C.sch, mountingholes.sch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]
2014-12-08 add values to R302, R303, R305, minor cosmetic fixes, add vias to ground plane
    [CMV2000.sch, I2C.sch, stereo_vision_cmv2000.kicad_pcb]
2014-12-09 add OSHW logo, cleanup silkscreen
    [stereo_vision_cmv2000.kicad_pcb, stereo_vision_cmv2000.sch]
2014-12-25 add c-mount design files as they were manufactured
    [c-mount.stl, c-mount.stp]
2019-06-01 original state (BUGGY, DO NOT USE)
    [cmv2000-fmc.kicad_pcb, cmv2000-fmc.sch]
2019-06-01 fixes for modern KiCad (v5) (BUGGY, DO NOT USE)
    [cmv2000-fmc.sch]
2019-07-05 fix mirrored JAE connectors (P2 and P3), correct signal names
    [cmv2000-fmc.kicad_pcb, cmv2000-fmc.sch]
2019-07-05 fixes for modern KiCad (v5)
    [CMV2000.sch, I2C.sch, mountingholes.sch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]
2019-07-05 move project-specific schematic symbols to symbols/ subdirectory
2019-09-23 major updates to schematic
    * add DC/DC converter to generate camera supply from 12V provided by FMC
    * enable camera supply only after FPGA supply is up
    * report camera supply status to FPGA
    * add level shifters for all single-ended signals
    * enable single-ended signals to camera only after camera supply is up
    * make sure single-ended signals to camera have well-defined value while
    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
    [cmv2000-fmc.sch]
2019-09-23 first version of layout (still WIP)
    [cmv2000-fmc.kicad_pcb, cmv2000-fmc.sch]
2019-09-23 update Samtec FMC ASP-134604-01 connector
    [cmv2000-fmc.kicad_pcb, cmv2000-fmc.sch]
2019-09-23 replace custom Hirose U.FL-R-SMT-1 footprint by upstream one
    [cmv2000-fmc.kicad_pcb, cmv2000-fmc.sch]
2019-09-23 add 3d models for Samtec TSM pin headers
    [TSM-102-01-L-SV.stp, TSM-105-01-L-DV.stp, cmv2000-fmc.kicad_pcb]
2019-09-23 work on layout, change high-frequency resistors to 0201
    [cmv2000-fmc.kicad_pcb, cmv2000-fmc.sch]
2019-09-23 slightly increase spacing between pin headers J2 and J9
    [cmv2000-fmc.kicad_pcb]
2019-09-23 use thermal relief on back side (except for U.FL connectors)
    [cmv2000-fmc.kicad_pcb]
2019-09-30 update to KiCad 5.1.4
    [cmv2000-fmc.kicad_pcb]
2019-09-30 fix incorrect pin names in FMC LPC symbol
    Unfortunately, KiCad re-ordered the pins in the file when saving, so the real diff is below:
    * pin C03: DP0_C2M_P -> DP0_C2M_N
    * pin D35: GA0 -> GA1
2019-09-30 use R27 and R28 as voltage divider at voltage detector (U3) output
    [cmv2000-fmc.kicad_pcb, cmv2000-fmc.sch]
2019-09-30 add optional bootstrap diode, as recommended by AP3211 appnote
    [cmv2000-fmc.kicad_pcb, cmv2000-fmc.sch]
2019-09-30 fix two courtyard DRC problems
    [cmv2000-fmc.kicad_pcb]
2019-10-02 fix settings for zones on inner layers
    [cmv2000-fmc.kicad_pcb]
2019-10-02 more tweaking, change export settings
    [cmv2000-fmc.kicad_pcb]
2020-12-23 move sensor board into subdirectory
    [CMV2000.sch, I2C.sch, cmv2000-sensor.kicad_pcb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]
2020-12-23 move FMC board into subdirectory
    [TSM-102-01-L-SV.stp, TSM-105-01-L-DV.stp, cmv2000-fmc.kicad_pcb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]
